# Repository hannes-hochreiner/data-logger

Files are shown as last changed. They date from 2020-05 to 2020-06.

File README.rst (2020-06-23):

data-logger
===========

Gadget writing sensor data to an SD card.

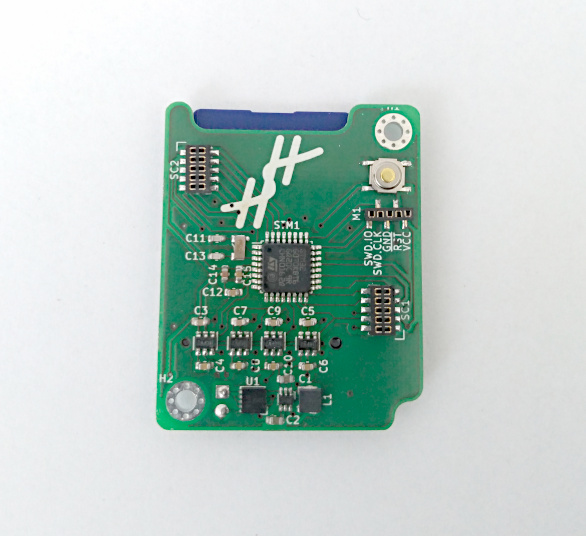
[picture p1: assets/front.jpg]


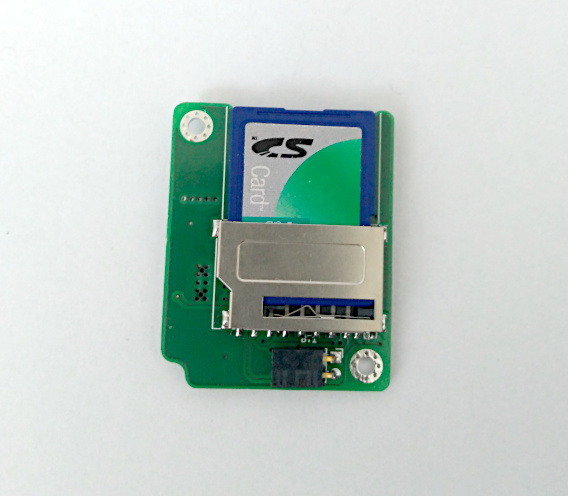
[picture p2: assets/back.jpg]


Assembly Snapshots
==================
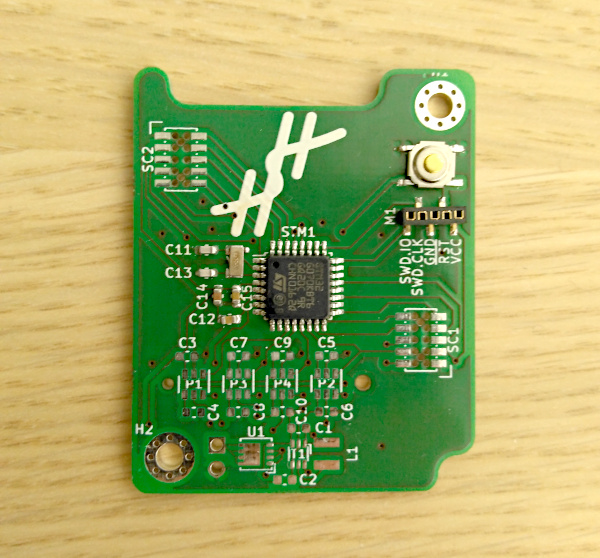
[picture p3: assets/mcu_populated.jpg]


Tests
=====

+---------------------------+--------------+
|unit                       |    status    |
+===========================+==============+
|SWD                        |      OK      |
+---------------------------+--------------+
|external clock             |      OK      |
+---------------------------+--------------+
|step-up power converter    |      OK      |
+---------------------------+--------------+
|reverse polarity protection|      OK      |
+---------------------------+--------------+
|communication with SD card |      OK      |
+---------------------------+--------------+
|reading files from SD card |      OK      |
+---------------------------+--------------+
|writing files to SD card   |      OK      |
+---------------------------+--------------+
|communication with sensors |      OK      |
+---------------------------+--------------+

Improvement Ideas
=================

* a status LED would be helpful
* connect the card detection
* power switch for the SD card

References
==========
`FATFS <http://elm-chan.org/fsw/ff/00index_e.html>`_

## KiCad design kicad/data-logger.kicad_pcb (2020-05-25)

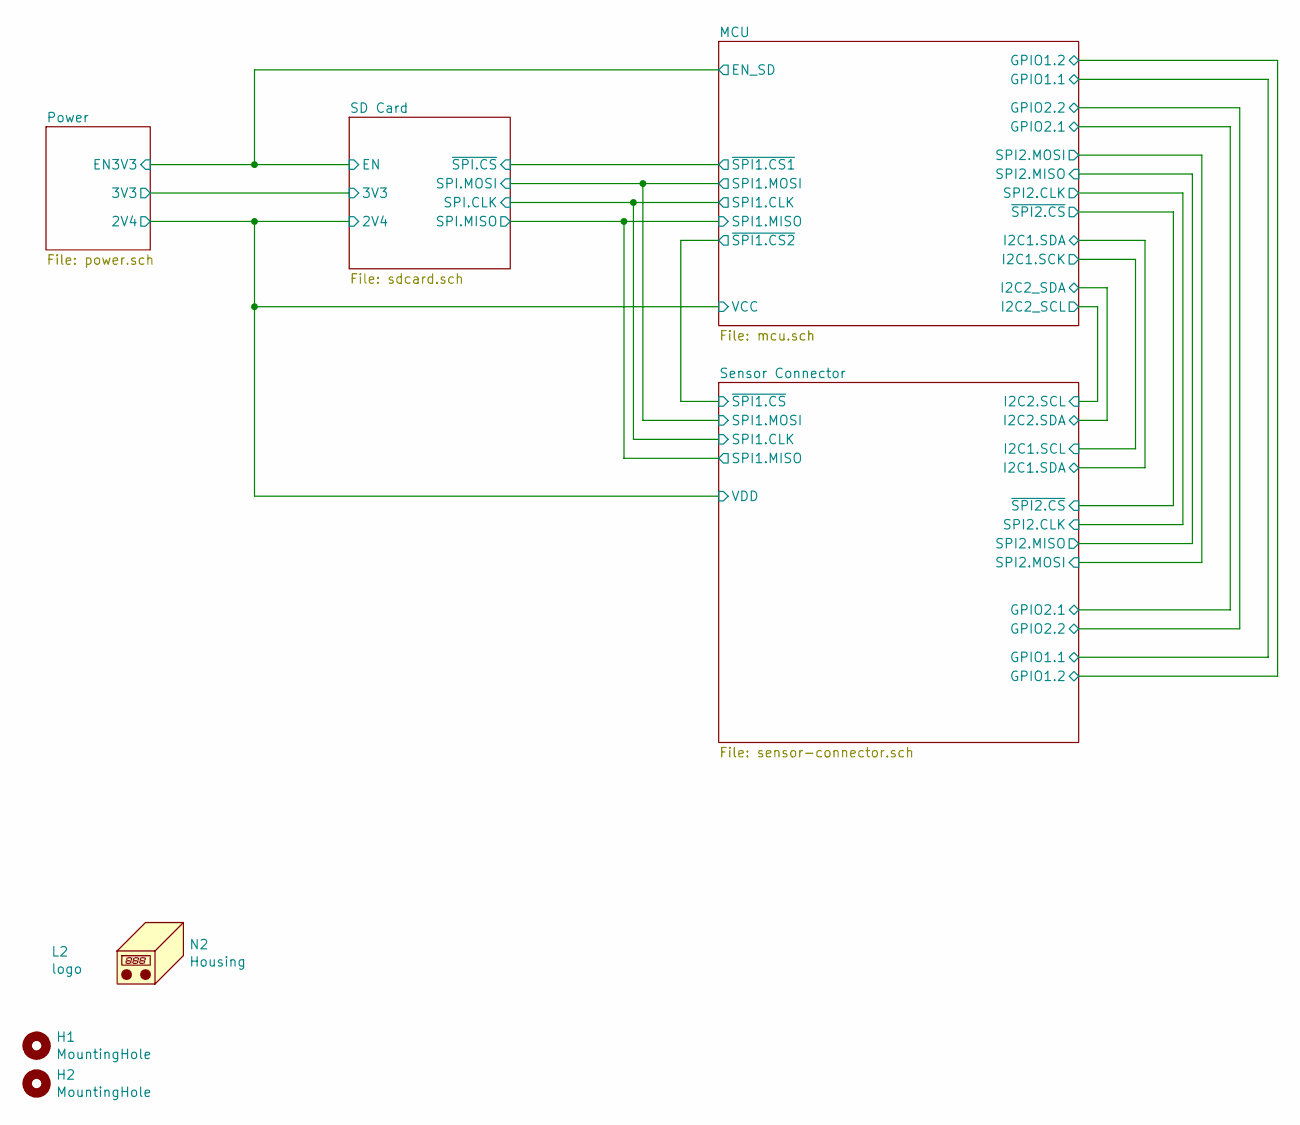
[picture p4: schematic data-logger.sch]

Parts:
H1, H2: MountingHole; MountingHole_2.7mm_M2.5_Pad_Via
L2: logo
N2: Housing; pcb_outline

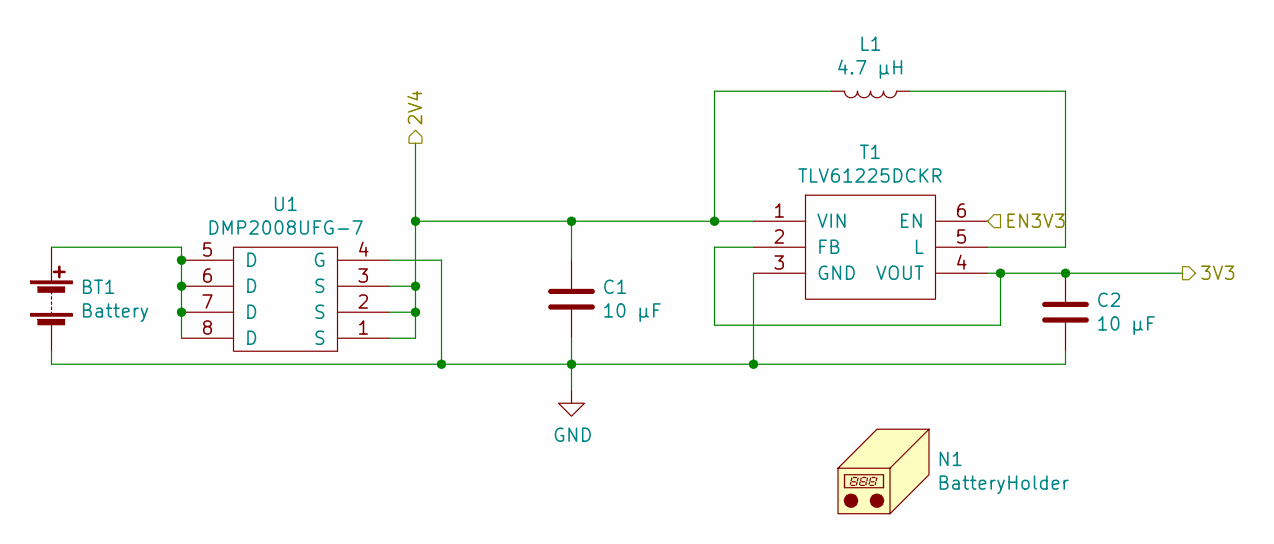
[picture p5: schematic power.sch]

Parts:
BT1: Battery; PinSocket_1x02_P2.54mm_Horizontal; DigiKey_PartNumber SAM1225-02-ND
C1, C2: 10 µF; C_0603_1608Metric
L1: 4.7 µH; LQH3NPN4R7MMEL; DigiKey_PartNumber 490-15954-1-ND
N1: BatteryHolder; MPD_BC2AAAL; DigiKey_PartNumber BC2AAAL-ND
T1: TLV61225DCKR; DigiKey_PartNumber 296-36756-1-ND
U1: DMP2008UFG-7; DigiKey_PartNumber DMP2008UFG-7DICT-ND

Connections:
/Power/2V4: C1.1, L1.2, T1.1 (VIN), U1.1 (S), U1.2 (S), U1.3 (S); also elsewhere on the board
/Power/3V3: C2.1, T1.2 (FB), T1.4 (VOUT); also elsewhere on the board
/SD Card/EN: T1.6 (EN); also elsewhere on the board
GND: BT1.2 (-), C1.2, C2.2, T1.3 (GND), U1.4 (G); also elsewhere on the board
unnamed: BT1.1 (+), U1.5 (D), U1.6 (D), U1.7 (D), U1.8 (D)
unnamed: L1.1, T1.5 (L)

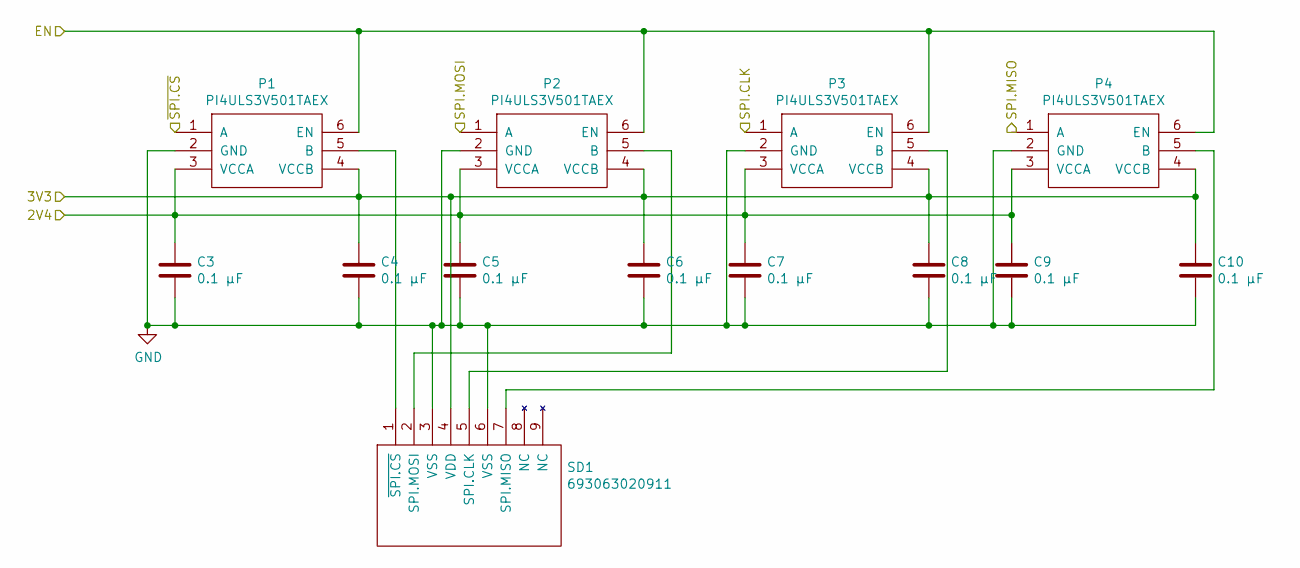
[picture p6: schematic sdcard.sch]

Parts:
C3, C4, C5, C6, C7, C8, C9, C10: 0.1 µF; C_0603_1608Metric
P1, P2, P3, P4: PI4ULS3V501TAEX; SOT-23-6; DigiKey_PartNumber PI4ULS3V501TAEXDICT-ND
SD1: 693063020911; DigiKey_PartNumber 732-3818-1-ND

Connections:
/Power/2V4: C3.1, C5.1, C7.1, C9.1, P1.3 (VCCA), P2.3 (VCCA), P3.3 (VCCA), P4.3 (VCCA); also elsewhere on the board
/Power/3V3: C4.1, C6.1, C8.1, C10.1, P1.4 (VCCB), P2.4 (VCCB), P3.4 (VCCB), P4.4 (VCCB), SD1.4 (VDD); also elsewhere on the board
/SD Card/EN: P1.6 (EN), P2.6 (EN), P3.6 (EN), P4.6 (EN); also elsewhere on the board
/SD Card/SPI.CLK: P3.1 (A); also elsewhere on the board
/SD Card/SPI.MISO: P4.1 (A); also elsewhere on the board
/SD Card/SPI.MOSI: P2.1 (A); also elsewhere on the board
/SD Card/~SPI.CS: P1.1 (A); also elsewhere on the board
GND: C3.2, C4.2, C5.2, C6.2, C7.2, C8.2, C9.2, C10.2, P1.2 (GND), P2.2 (GND), P3.2 (GND), P4.2 (GND), SD1.3 (VSS), SD1.6 (VSS); also elsewhere on the board
unnamed: P1.5 (B), SD1.1 (~SPI.CS)
unnamed: P2.5 (B), SD1.2 (SPI.MOSI)
unnamed: P3.5 (B), SD1.5 (SPI.CLK)
unnamed: P4.5 (B), SD1.7 (SPI.MISO)

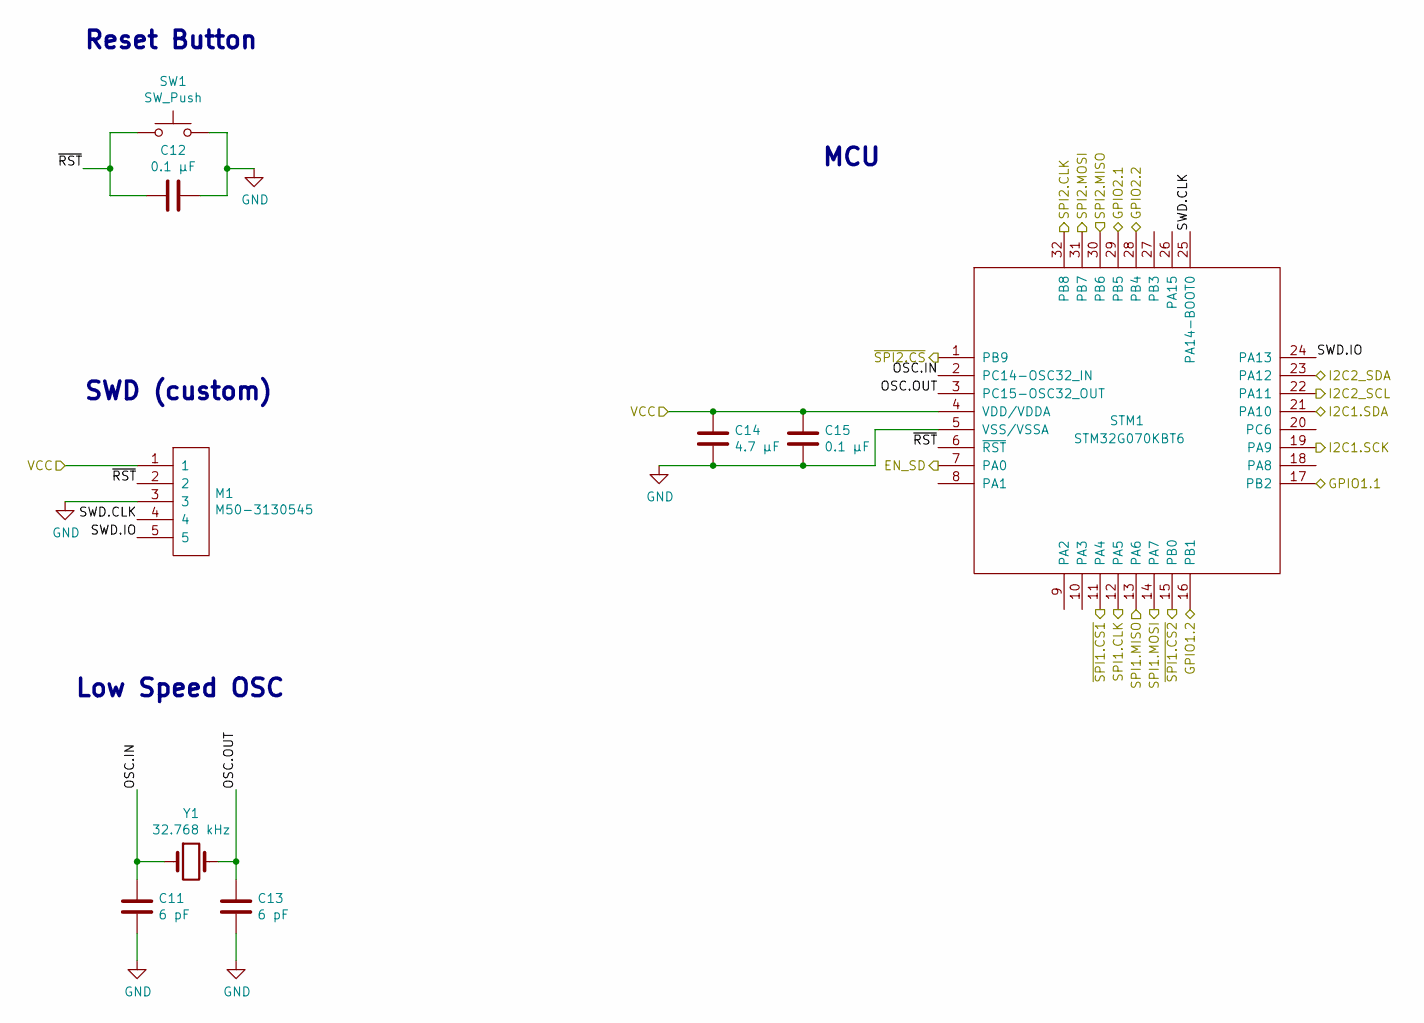
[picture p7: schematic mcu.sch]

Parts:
C11, C13: 6 pF; C_0603_1608Metric; DigiKey_PartNumber 311-1055-1-ND
C12, C15: 0.1 µF; C_0603_1608Metric
C14: 4.7 µF; C_0603_1608Metric
M1: M50-3130545; Manufacturer_PartNumber M50-3130545; DigiKey_PartNumber 952-3585-ND
STM1: STM32G070KBT6; LQFP-32_7x7mm_P0.8mm; DigiKey_PartNumber 497-STM32G070KBT6-ND
SW1: SW_Push; PTS526-SM15-SMTR2-LFS; DigiKey_PartNumber CKN12220-1-ND
Y1: 32.768 kHz; CM7V-T1A; DigiKey_PartNumber 2195-CM7V-T1A-32.768KHZ-6PF-20PPM-TA-QC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

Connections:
/MCU/GPIO1.1: STM1.17 (PB2); also elsewhere on the board
/MCU/GPIO1.2: STM1.16 (PB1); also elsewhere on the board
/MCU/GPIO2.1: STM1.29 (PB5); also elsewhere on the board
/MCU/GPIO2.2: STM1.28 (PB4); also elsewhere on the board
/MCU/I2C1.SCK: STM1.19 (PA9); also elsewhere on the board
/MCU/I2C1.SDA: STM1.21 (PA10); also elsewhere on the board
/MCU/OSC.IN: C11.1, STM1.2 (PC14-OSC32_IN), Y1.1
/MCU/OSC.OUT: C13.1, STM1.3 (PC15-OSC32_OUT), Y1.2
/MCU/SPI2.CLK: STM1.32 (PB8); also elsewhere on the board
/MCU/SPI2.MISO: STM1.30 (PB6); also elsewhere on the board
/MCU/SPI2.MOSI: STM1.31 (PB7); also elsewhere on the board
/MCU/SWD.CLK: M1.4, STM1.25 (PA14-BOOT0)
/MCU/SWD.IO: M1.5, STM1.24 (PA13)
/MCU/~RST: C12.2, M1.2, STM1.6 (~RST), SW1.1
/MCU/~SPI2.CS: STM1.1 (PB9); also elsewhere on the board
/Power/2V4: C14.1, C15.1, M1.1, STM1.4 (VDD/VDDA); also elsewhere on the board
/SD Card/EN: STM1.7 (PA0); also elsewhere on the board
/SD Card/SPI.CLK: STM1.12 (PA5); also elsewhere on the board
/SD Card/SPI.MISO: STM1.13 (PA6); also elsewhere on the board
/SD Card/SPI.MOSI: STM1.14 (PA7); also elsewhere on the board
/SD Card/~SPI.CS: STM1.11 (PA4); also elsewhere on the board
/Sensor Connector/I2C2.SCL: STM1.22 (PA11); also elsewhere on the board
/Sensor Connector/I2C2.SDA: STM1.23 (PA12); also elsewhere on the board
/Sensor Connector/~SPI1.CS: STM1.15 (PB0); also elsewhere on the board
GND: C11.2, C12.1, C13.2, C14.2, C15.2, M1.3, STM1.5 (VSS/VSSA), SW1.2; also elsewhere on the board

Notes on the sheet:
SWD (custom)
Reset Button
Low Speed OSC
MCU

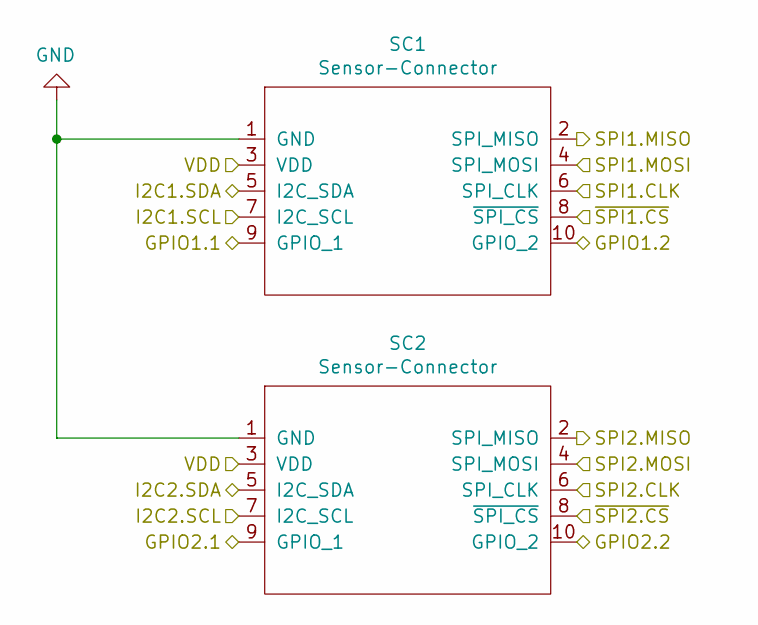
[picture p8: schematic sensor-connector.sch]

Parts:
SC1, SC2: Sensor-Connector; M50-3150542R

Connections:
/MCU/GPIO1.1: SC1.9 (GPIO_1); also elsewhere on the board
/MCU/GPIO1.2: SC1.10 (GPIO_2); also elsewhere on the board
/MCU/GPIO2.1: SC2.9 (GPIO_1); also elsewhere on the board
/MCU/GPIO2.2: SC2.10 (GPIO_2); also elsewhere on the board
/MCU/I2C1.SCK: SC1.7 (I2C_SCL); also elsewhere on the board
/MCU/I2C1.SDA: SC1.5 (I2C_SDA); also elsewhere on the board
/MCU/SPI2.CLK: SC2.6 (SPI_CLK); also elsewhere on the board
/MCU/SPI2.MISO: SC2.2 (SPI_MISO); also elsewhere on the board
/MCU/SPI2.MOSI: SC2.4 (SPI_MOSI); also elsewhere on the board
/MCU/~SPI2.CS: SC2.8 (~SPI_CS); also elsewhere on the board
/Power/2V4: SC1.3 (VDD), SC2.3 (VDD); also elsewhere on the board
/SD Card/SPI.CLK: SC1.6 (SPI_CLK); also elsewhere on the board
/SD Card/SPI.MISO: SC1.2 (SPI_MISO); also elsewhere on the board
/SD Card/SPI.MOSI: SC1.4 (SPI_MOSI); also elsewhere on the board
/Sensor Connector/I2C2.SCL: SC2.7 (I2C_SCL); also elsewhere on the board
/Sensor Connector/I2C2.SDA: SC2.5 (I2C_SDA); also elsewhere on the board
/Sensor Connector/~SPI1.CS: SC1.8 (~SPI_CS); also elsewhere on the board
GND: SC1.1 (GND), SC2.1 (GND); also elsewhere on the board

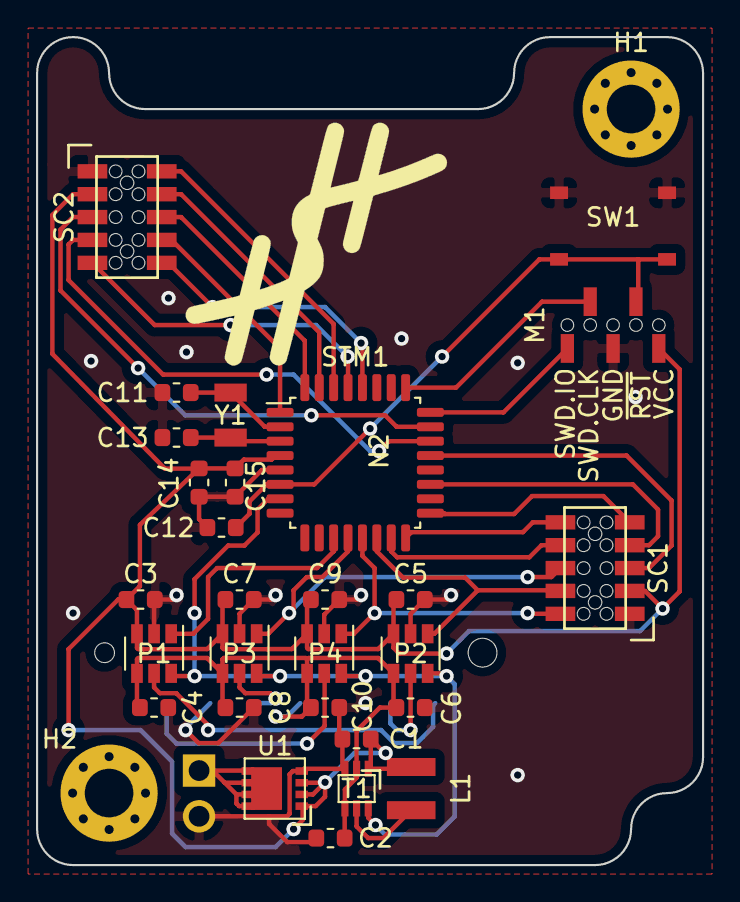
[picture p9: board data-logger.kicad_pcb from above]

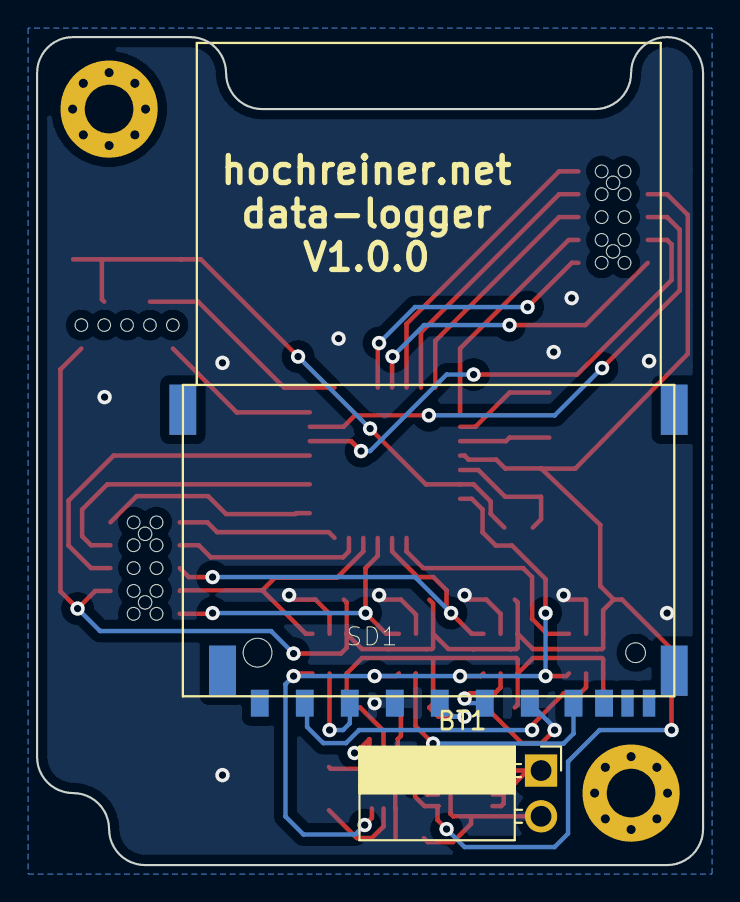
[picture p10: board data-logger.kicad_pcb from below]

Board: 2 copper layers, 37.0 x 46.0 mm, 35 parts (3 on the bottom side), 32 nets.

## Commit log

2020-05-24 initial design completed
    [data-logger.kicad_pcb, data-logger.sch, mcu.sch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]
2020-05-25 added reverse polarization protection
    [data-logger.kicad_pcb, power.sch]
2020-05-25 tweaks after drc
    [data-logger.kicad_pcb, power.sch]
2020-05-25 updated sensor connector footprint
    [data-logger.kicad_pcb]
2020-05-25 added label
    [data-logger.kicad_pcb]
2020-05-25 added labels
    [data-logger.kicad_pcb]
2020-05-25 switched the size of C14
    [data-logger.kicad_pcb, mcu.sch]
2020-06-23 updated sensor test status
